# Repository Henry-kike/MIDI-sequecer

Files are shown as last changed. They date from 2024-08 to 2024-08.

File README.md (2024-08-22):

# MIDI-sequecer
***Simple polyphonic MIDI sequencer based in the esp32 with oled display***



I'm looking to combine the best of sequencers like keystep pro and op-1. I make animations for the diferent mode of my sequencer (inspired in the op-1) and i work on adding two track (like keystep pro). The sequencer can save and play chords sequences and i want to add song mode which could play a sequence in different starting notes. Then i will work on playing two sequence simultaneusly, firts on two different MIDI chanels and later in two phisycal MIDI ports.



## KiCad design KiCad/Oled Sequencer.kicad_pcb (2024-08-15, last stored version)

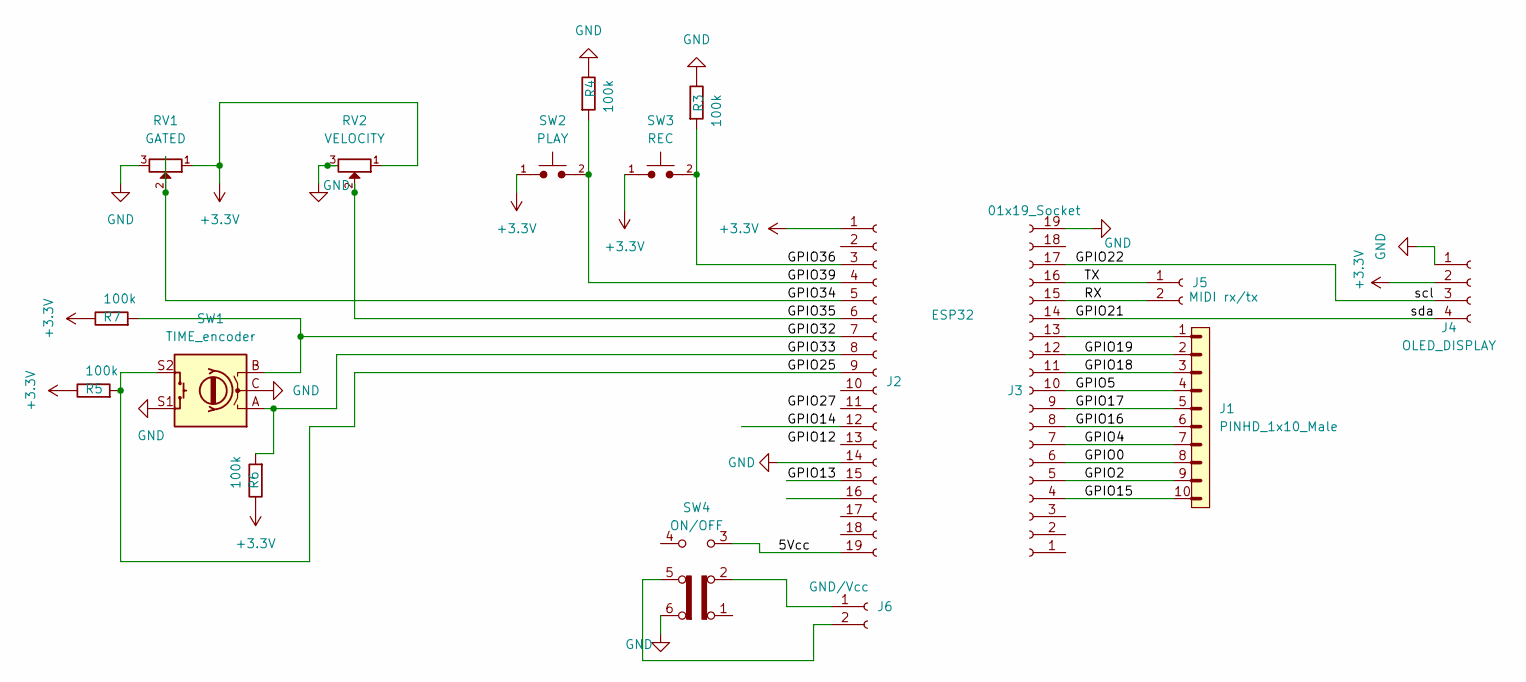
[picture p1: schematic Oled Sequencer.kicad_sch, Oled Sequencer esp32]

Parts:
J1: PINHD_1x10_Male; PinHeader_1x10_P2.54mm_Vertical
J2: ESP32; PinSocket_1x19_P2.54mm_Vertical
J3: 01x19_Socket; PinSocket_1x19_P2.54mm_Vertical
J4: OLED_DISPLAY; PinHeader_1x04_P2.54mm_Vertical
J5: MIDI rx/tx; PinHeader_1x02_P2.54mm_Vertical
J6: GND/Vcc; PinHeader_1x02_P2.54mm_Vertical
R3, R4, R5, R6, R7: 100k; R_Axial_DIN0207_L6.3mm_D2.5mm_P10.16mm_Horizontal
RV1: GATED; Potentiometer_Bourns_PTA2043_Single_Slide
RV2: VELOCITY; Potentiometer_Bourns_PTA2043_Single_Slide
SW1: TIME_encoder; RotaryEncoder_Alps_EC11E-Switch_Vertical_H20mm
SW2: PLAY; SW_PUSH_6mm
SW3: REC; SW_PUSH_6mm
SW4: ON/OFF; SW_E-Switch_EG1271_SPDT

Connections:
+3.3V: J2.1, J4.2, R5.2, R6.2, R7.2, RV1.1, RV2.1, SW2.1, SW3.1
/5Vcc: J2.19, SW4.3 (C)
/GPIO0: J1.8, J3.6
/GPIO2: J1.9, J3.5
/GPIO4: J1.7, J3.7
/GPIO5: J1.4, J3.10
/GPIO13: J2.15
/GPIO14: J2.12
/GPIO15: J1.10, J3.4
/GPIO16: J1.6, J3.8
/GPIO17: J1.5, J3.9
/GPIO18: J1.3, J3.11
/GPIO19: J1.2, J3.12
/GPIO21: J3.14, J4.4
/GPIO22: J3.17, J4.3
/GPIO25: J2.9, R5.1, SW1.S2
/GPIO32: J2.7, R7.1, SW1.B
/GPIO33: J2.8, R6.1, SW1.A
/GPIO34: J2.5, RV1.2
/GPIO35: J2.6, RV2.2
/GPIO36: J2.3, R3.1, SW3.2
/GPIO39: J2.4, R4.1, SW2.2
/RX: J3.15, J5.2
/TX: J3.16, J5.1
GND: J2.14, J3.19, J4.1, R3.2, R4.2, RV1.3, RV2.3, SW1.C, SW1.S1, SW4.6 (C)
unnamed: J1.1, J3.13
unnamed: J6.1, SW4.2 (B)
unnamed: J6.2, SW4.5 (B)

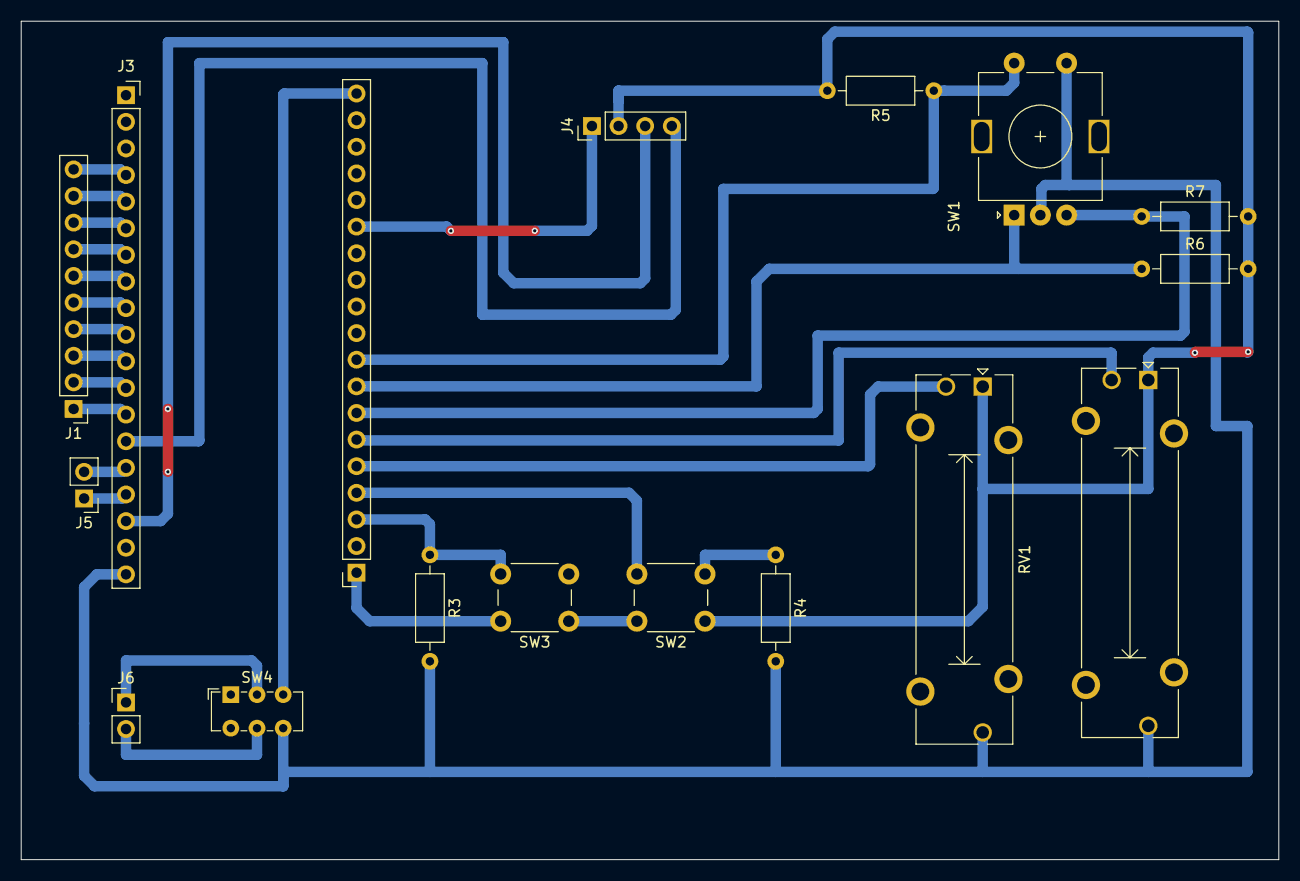
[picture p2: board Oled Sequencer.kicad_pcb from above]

Board: 2 copper layers, 120.0 x 80.0 mm, 17 parts (0 on the bottom side), 26 nets.

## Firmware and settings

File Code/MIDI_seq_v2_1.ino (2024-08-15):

#include "config.h"
#include <MIDI.h>
#include "oled.h"
constexpr bool REC_BUTTON = false;
constexpr bool PLAY_BUTTON = true;

// Declarar el mutex
SemaphoreHandle_t xMutex;
MIDI_CREATE_INSTANCE(HardwareSerial, Serial, midi2);

// Definición de la enumeración para los modos del secuenciador
enum SequencerMode {
  REC_MODE,  // 0
  PLAY_MODE, // 1
  STOP_MODE  // 2
};
//GLOBALS
uint8_t  notes[MAX_NOTES] = {0};  //save the pitch separa con ceros los acordes
uint8_t count=0; //for display and others
uint8_t play_counter=0; //for display numbers in play mode
uint8_t notes_played = 0;
uint8_t notes_press_num = 1;
uint8_t midi_channel = 1;
uint8_t vel_value = 100;
unsigned long sustain = 1200000;
bool is_pressed = false;
volatile uint8_t bpm = 120;
volatile uint8_t figure = QUARTER_NOTE;
volatile bool pressButton = REC_BUTTON; //false = recButton, true = playButton
volatile bool shared_val = false;
volatile bool encoder_change = false;
volatile unsigned long last_interrupt = 0; 
volatile bool encoderButton = false;
unsigned long note_duration = NOTE_DURATION(bpm,figure);
// Variable para almacenar el modo actual del secuenciador
SequencerMode currentMode = REC_MODE;
//INTERRUPT
void IRAM_ATTR play_press();
void IRAM_ATTR rec_press();
void IRAM_ATTR encoder();
void IRAM_ATTR encoder_push();



// Declarar la tarea segundo nucleo
void read_and_display(void *parameter);

//FUNCIONES
int play_notes1(uint8_t notes[], uint8_t channel);
void play_notes(uint8_t *current_note);
void send_notes(uint8_t  **current_note, uint8_t velocity, uint8_t channel, bool prev_val);
void play_sequence();
void stop_sequence();
void rec_sequence();
void rec_reset(bool reset_all);
void add_silence();
void reset_MIDI();
void handleNoteOn(byte channel, byte pitch, byte velocity);
void handleNoteOff(byte channel, byte pitch, byte velocity);
unsigned long sustain_calcule(unsigned long blck);
uint8_t velocity_calcule();

void setup() {
  // Crear el mutex
  xMutex = xSemaphoreCreateMutex();
  // Crear la tarea para actualizar el display OLED en el segundo núcleo
  xTaskCreatePinnedToCore(read_and_display, "Update Display and read values", 4096, NULL, 1, NULL, 0);

  pinMode (LED_BUILTIN, OUTPUT);
  pinMode(PLAY_SWT, INPUT);//pulsador play
  pinMode(REC_SWT, INPUT);//pulsador rec  
  pinMode(ENCODER_SWT, INPUT);
  pinMode(DT, INPUT);
  pinMode(CLK, INPUT);
  pinMode(GATE_PIN,INPUT);
  
  midi2.setHandleNoteOn(handleNoteOn);  // Put only the name of the function       
  midi2.setHandleNoteOff(handleNoteOff);// Do the same for NoteOffs  
  midi2.begin(MIDI_CHANNEL_OMNI);// Initiate MIDI communications, listen to all channels 
  midi2.turnThruOff();   
  attachInterrupt(digitalPinToInterrupt(PLAY_SWT),play_press,FALLING);
  attachInterrupt(digitalPinToInterrupt(REC_SWT),rec_press,FALLING);  
  attachInterrupt(digitalPinToInterrupt(ENCODER_SWT),encoder_push,FALLING); 
  attachInterrupt(digitalPinToInterrupt(CLK),encoder,FALLING);

  display_ini();
  //show hello
  show_intro();  
  rec_sequence();
}



void loop() {
  
  if (pressButton == REC_BUTTON){
    switch(currentMode){
      case REC_MODE:
      rec_reset(true);
      rec_sequence();
      break;

      case PLAY_MODE:
      currentMode = REC_MODE;
      rec_reset(false);
      rec_sequence();
      break;

      case STOP_MODE:
      currentMode = REC_MODE;
      rec_reset(false);
      rec_sequence();
      break;
    }      
  } else{//play pressed
      switch(currentMode){
        case REC_MODE:
        currentMode = PLAY_MODE;
        play_sequence();
        break;

        case PLAY_MODE:
        currentMode = STOP_MODE;
        stop_sequence();
        break;

        case STOP_MODE:
        currentMode = PLAY_MODE;
        play_sequence();
        break;

      }
      
    }

  delay(100); // Añadir un pequeño retardo para evitar rebotes
}

//SUB-MODES
void play_sequence(){
  midi2.setInputChannel(MIDI_CHANNEL_OFF);
  //show_play();
  play_notes(notes);      
  reset_MIDI(); 
}
void stop_sequence(){
  bool prev_val = shared_val;
  
  //show_stop();   
  while(prev_val == shared_val){
    while (Serial.available()>0)  Serial.read();
  } 
}
void rec_sequence(){
  bool prev_val = shared_val;
  show_number(0, true);
  while (prev_val == shared_val){
    midi2.read(MIDI_CHANNEL_OMNI);
    if(encoderButton == true){  //agregar silencio
      add_silence();
      encoderButton = false;    
    }  
  } 
}
void rec_reset(bool reset_all){
  if (reset_all){
    for (int i=0; i<MAX_NOTES; i++){
    notes[i] =  0;
    }
    show_number(0,true);
    digitalWrite(LED_BUILTIN, HIGH);
    delay(200);
    digitalWrite(LED_BUILTIN, LOW);
  }
  
  notes_played = 0;
  count = 0;
  
}

//  SAVE NOTES
void handleNoteOn(byte channel, byte pitch, byte velocity){  
  if (notes_played < (MAX_NOTES-1)){
    notes[notes_played] = pitch;
    notes_played++;

    if (is_pressed == false){
      count++;  
      show_number(count, true);
    }
  }
  else{
    void show_max_notes();
  }  
  is_pressed = true;
}

void handleNoteOff(byte channel, byte pitch, byte velocity){
  if (is_pressed == true && notes_played < MAX_NOTES){ 
    notes[notes_played] = 0;
    notes_played++;
  }
  if (count == 1) midi_channel = channel; //guarda el canal de la primera nota
  is_pressed = false;
}

//  PLAY NOTES  (reproduce en bucle la secuencia hasta que playButton == false)
int play_notes1(uint8_t notes[], uint8_t channel){
  
  uint8_t velocity;
  unsigned long prev_time = 0, sustain_start = 0,sustain_time, note_time;
  bool prev_val = shared_val;  
  uint8_t i = 0, j = 0;
  //Asignacion incial de valores
  if (xSemaphoreTake(xMutex, portMAX_DELAY)) {
      note_time = note_duration;
      sustain_time = sustain;
      velocity = vel_value;
      xSemaphoreGive(xMutex);
    }
  
  while(prev_val == shared_val){
    //tiempo hasta la nota siguiente    
    if((micros() - prev_time) >= note_time){//si cumple un periodo
      prev_time = micros();
       //delay(300);   
      //Encendido de las notas
      while(notes[i] != 0){
        midi2.sendNoteOn(notes[i],vel_value,channel);
        delayMicroseconds(1);//tiempo entre nota y nota, ARPEGIAR (50000)
        i++;
      }
      //SUSTAIN
      sustain_start = micros(); // Usamos una nueva variable para el tiempo de sustain
      //actualizo valores de sustain
      if (xSemaphoreTake(xMutex, portMAX_DELAY)) {
        sustain_time = sustain ;
        xSemaphoreGive(xMutex);
      }
      while ((micros() - sustain_start) <= sustain_time){       
        if (prev_val != shared_val){//si saliste del modo play
          while(notes[j] != 0){//apaga las notas
            midi2.sendNoteOff(notes[j],0,channel);
            delayMicroseconds(1);
            j++;
          }
          return 0;  
        }    
      }
      //apagado de las notas
      while(notes[j] != 0){
        midi2.sendNoteOff(notes[j],0,channel);
        delayMicroseconds(1);
        j++;
      }
      if (xSemaphoreTake(xMutex, portMAX_DELAY)) {
        note_time = note_duration;
        velocity = vel_value;
        play_counter++;
        xSemaphoreGive(xMutex);
      }
      
  if (play_counter >= count){//si termina de tocar todas las notas
    i = 0;
    j = 0;
    play_counter = 0;
  }

      else if (i < MAX_NOTES) {//pasar sobre el cero, avanzar siguiente grupo
        i++;
        j++;     
      }
      
    }
  }
  return 0;
}
void play_notes(uint8_t *current_note){
  uint8_t velocity;
  unsigned long prev_time = 0, note_time;
  bool prev_val = shared_val;  
  
  //Asignacion incial de valores
  if (xSemaphoreTake(xMutex, portMAX_DELAY)) {
      note_time = note_duration;
      velocity = vel_value;
      play_counter = 0;
      xSemaphoreGive(xMutex);
    }
  
  while(prev_val == shared_val){
    //tiempo hasta la nota siguiente    
    if((micros() - prev_time) >= note_time){//si cumple un periodo
      prev_time = micros();

      //Encendido de las notas  
      send_notes(&current_note, velocity, midi_channel, prev_val);

      //actualizo variables
      if (xSemaphoreTake(xMutex, portMAX_DELAY)) {
      note_time = note_duration;
      velocity = vel_value;
      play_counter++;
      current_note++; //warning
      if (play_counter >= count){//si termina de tocar todas las notas   
        play_counter = 0;
        current_note = notes; //reinicia el puntero
      }
      xSemaphoreGive(xMutex);
    }
    }  
  }
}
void send_notes(uint8_t  **current_note, uint8_t velocity, uint8_t channel, bool prev_val){
  unsigned long sustain_start = 0, sustain_time;
  uint8_t *start_note = *current_note;
  while(**current_note != 0){
    midi2.sendNoteOn(**current_note,velocity,channel);
    delayMicroseconds(1);//tiempo entre nota y nota, ARPEGIAR (50000)
    (*current_note)++;
  } 
  //SUSTAIN
  sustain_start = micros(); // Usamos una nueva variable para el tiempo de sustain
  //actualizo valores de sustain
  if (xSemaphoreTake(xMutex, portMAX_DELAY)) {
    sustain_time = sustain ;
    
    xSemaphoreGive(xMutex);
  }
  while ((micros() - sustain_start) <= sustain_time){       
    if (prev_val != shared_val){//si saliste del modo play
      while(*start_note != 0){//apaga las notas
        midi2.sendNoteOff(*start_note,0,channel);
          //delayMicroseconds(1);
          start_note++;
      } 
    }    
  }
  //apagado de las notas
  while(*start_note != 0){//apaga las notas
    midi2.sendNoteOff(*start_note,0,channel);
    //delayMicroseconds(1);
    start_note++;
  }     

}

void add_silence(){
  count++;    
  show_number(count, true);
  if (notes_played < (MAX_NOTES-1)){
    notes[notes_played]=0;
    notes_played++;
  }
  else{
    show_max_notes();
  }
}

void reset_MIDI(){
  while (Serial.available()>0)  Serial.read();
  midi2.begin(MIDI_CHANNEL_OMNI);//reinicia el midi para borrar buffer
  midi2.turnThruOff();  //hay que volverle a decir     
}


//  INTERRUPCIONES:
void IRAM_ATTR play_press(){
  if(millis()-last_interrupt >300)
  {
    pressButton = PLAY_BUTTON;
    shared_val = !shared_val;
    
  }
  last_interrupt=millis();  
}
void IRAM_ATTR rec_press(){
  if(millis()-last_interrupt >300)
  {
    pressButton = REC_BUTTON;
    shared_val = !shared_val;
    
  }
  last_interrupt=millis();  
}

void IRAM_ATTR encoder() {
  if (millis() - last_interrupt > 90) {
    if (xSemaphoreTakeFromISR(xMutex, NULL)) {
      if (digitalRead(DT) == HIGH && bpm < BPM_MAX) {
        bpm++;
      } else if (bpm > BPM_MIN) {
        bpm--;
      }
      encoder_change = true;
      xSemaphoreGiveFromISR(xMutex, NULL);
    }
    last_interrupt = millis();
  }
}

void IRAM_ATTR encoder_push(){
  if(pressButton==REC_BUTTON){  //modo rec
    if(millis()-last_interrupt >200)
    {
      encoderButton=true;  
      last_interrupt=millis();
    }
    
  }
  
  else { //modo play o stop
    encoder_change = true;
    if(millis()-last_interrupt >200)
    {
      if(figure < SIXTEENTH_NOTE){
        figure = figure*2;  
      }
      else{
        figure = WHOLE_NOTE;
      }
      last_interrupt=millis();
    }
  }
}

//SEGUNDO NUCLEO TASK
void read_and_display(void *parameter) {
  //Variables para actualizar el valor solo cuando cambia
  uint8_t currentBpm = bpm;
  uint8_t currentVel = vel_value, oldVel = currentVel;
  uint8_t oldCounter = 0;
  
  
  while (true) {
    // Esperar a que el semáforo sea liberado
    if (encoder_change) {
      update_clock(&currentBpm);
    }

    if (currentMode != REC_MODE){

      if(currentMode == PLAY_MODE){
        if (xSemaphoreTake(xMutex, portMAX_DELAY)) {
          if (oldCounter != play_counter){
            show_number(play_counter+1, false);
            oldCounter = play_counter;
          }          
        xSemaphoreGive(xMutex);
        }
      } 
      else{
        show_stop();
      }
      //VELOCITY
      currentVel = velocity_calcule();
      if (currentVel != oldVel){
      if (xSemaphoreTake(xMutex, portMAX_DELAY)) {
          vel_value = currentVel;       
          xSemaphoreGive(xMutex);
        }
        oldVel = currentVel;
      }
        
      if (xSemaphoreTake(xMutex, portMAX_DELAY)) {
        sustain = sustain_calcule(note_duration);        
        xSemaphoreGive(xMutex);
      }     
    }  

    // Añadir un pequeño delay para evitar actualizaciones excesivas
    vTaskDelay(100 / portTICK_PERIOD_MS);
  }
}
///////////////

void play_sequence_2core(){

}

void update_clock(uint8_t *current_bpm){
  if (xSemaphoreTake(xMutex, portMAX_DELAY)) {
    *current_bpm = bpm;
    note_duration = NOTE_DURATION(*current_bpm, figure);
    encoder_change = false;
    xSemaphoreGive(xMutex);
  }

  show_bpm(*current_bpm);
}
/*
void update_velocity_sustain(){
  //VELOCITY
  currentVel = velocity_calcule();
  if (currentVel != oldVel){
   if (xSemaphoreTake(xMutex, portMAX_DELAY)) {
      vel_value = currentVel;       
      xSemaphoreGive(xMutex);
    }
    oldVel = currentVel;
  }
    
  if (xSemaphoreTake(xMutex, portMAX_DELAY)) {
    sustain = sustain_calcule(note_duration);        
    xSemaphoreGive(xMutex);
  }
}
*/
unsigned long sustain_calcule(unsigned long blck){
  unsigned long m;
  m=(0.8*blck)/4095;//0.8 -> 80%
  return (m*analogRead(GATE_PIN) + blck*GATE_MIN);
}

uint8_t velocity_calcule(){
  int vel = analogRead(VELOCITY_PIN);
  return map(vel, 0, 4096, 10, 127);
}

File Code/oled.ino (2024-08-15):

#include <U8g2lib.h>
#include <Wire.h>
#include <SPI.h>
#include "oled.h"
U8G2_SH1106_128X64_NONAME_F_HW_I2C u8g2(U8G2_R0);

void display_ini(){
  u8g2.begin();
}

void show_intro(void) {
  uint8_t i = 0;
  for (i=0; i<=31; i+=2){
    u8g2.clearBuffer();
    u8g2.setFontMode(1);
    u8g2.setBitmapMode(1);
    u8g2.drawFrame(62-2*i, 31-i, 4+4*i, 2+2*i);//origen
    u8g2.sendBuffer();
    delay(5);
  }
  u8g2.clearBuffer();
  u8g2.setFontMode(1);
  u8g2.setBitmapMode(1);
    u8g2.drawFrame(0, 0, 128, 64);//marco
    u8g2.setFont(u8g2_font_5x8_tr);
    u8g2.drawStr(55, 17, "MIDI");
    u8g2.setFont(u8g2_font_6x13_tr);
    u8g2.drawStr(38, 30, "SEQUENCER");  
    //keyboard:  
    u8g2.drawBox(34, 36, 61, 6);
    u8g2.drawBox(34, 43, 61, 14);
    u8g2.setDrawColor(2);
    u8g2.drawStr(34, 52, "||| || |||");
    u8g2.setFont(u8g2_font_4x6_tr);
    u8g2.drawStr(36, 57, "|  |  |  |  |");
    u8g2.setFont(u8g2_font_6x13_tr);
    u8g2.drawStr(35, 52, "||| || |||");
    u8g2.drawStr(36, 52, "||| || |||");
    u8g2.setFont(u8g2_font_4x6_tr);
    u8g2.drawStr(42, 57, "|  |  |");
    u8g2.drawStr(78, 57, "|  |");
    u8g2.setFont(u8g2_font_6x12_tr);
    u8g2.drawStr(53, 51, "|  |");
  u8g2.sendBuffer();
  delay(3000);
}

void show_play(){
  u8g2.clearBuffer();
  u8g2.setFontMode(1);
  u8g2.setBitmapMode(1);
  u8g2.setFont(u8g2_font_spleen32x64_mf);
  u8g2.drawStr(2, 54, "PLAY");
  u8g2.sendBuffer();
}

void show_stop(){
  u8g2.clearBuffer();
  u8g2.setFontMode(1);
  u8g2.setBitmapMode(1);
  u8g2.setFont(u8g2_font_spleen32x64_mf);
  u8g2.drawStr(2, 54, "STOP");
  u8g2.sendBuffer();
}

void show_number(uint8_t num, bool rec_on){
  char num_char[4];
  itoa(num, num_char, 10);
  u8g2.clearBuffer();
  u8g2.setFontMode(1);
  u8g2.setBitmapMode(1);
  u8g2.setFont(u8g2_font_logisoso50_tf);
  if (num < 10) u8g2.drawStr(46, 60, num_char);
  else if(num >=10) u8g2.drawStr(28, 60, num_char);
  //rec icon 
  if (rec_on){
    u8g2.setDrawColor(1);
    u8g2.drawRBox(101, 0, 27, 7, 2);//rectangulo
    u8g2.setDrawColor(2);
    u8g2.drawEllipse(123, 3, 2, 2);//circulo
    u8g2.setFont(u8g2_font_4x6_tr);
    u8g2.drawStr(106, 6, "REC"); 
  }
      
  u8g2.sendBuffer();
}

void show_bpm(uint8_t bpm){
  char bpm_char[4];
  itoa(bpm, bpm_char, 10);
  u8g2.clearBuffer();
  u8g2.setFontMode(1);
  u8g2.setBitmapMode(1);
  //metronomo icon
  u8g2.drawFrame(13, 43, 18, 8);
  u8g2.drawLine(30, 44, 33, 40);
  u8g2.drawLine(30, 50, 33, 45);
  u8g2.drawLine(33, 41, 33, 44);
  u8g2.drawLine(13, 42, 21, 18);
  u8g2.drawLine(24, 18, 30, 42);
  u8g2.drawLine(21, 18, 23, 18);
  u8g2.drawLine(33, 40, 26, 16);
  u8g2.drawLine(23, 16, 25, 16);
  u8g2.drawLine(22, 43, 12, 24);
  u8g2.drawPixel(25, 18);
  u8g2.drawPixel(22, 17);
  //mesa
  u8g2.drawLine(0, 55, 48, 55);
  u8g2.drawLine(59, 32, 34, 32);
  u8g2.drawLine(48, 55, 60, 33);
  u8g2.drawLine(13, 32, 0, 32);
  //bpm
  u8g2.setFont(u8g2_font_spleen16x32_mf);
  u8g2.drawStr(72, 35, bpm_char);
  u8g2.setFont(u8g2_font_spleen8x16_mf);
  u8g2.drawStr(84, 51, "bpm");
  //
  u8g2.sendBuffer();
}

void show_max_notes()
{
  u8g2.clearBuffer();
  u8g2.setFontMode(1);
  u8g2.setBitmapMode(1);
  u8g2.setFont(u8g2_font_profont29_tr);
  u8g2.drawStr(49, 28, "NO");
  u8g2.drawStr(33, 54, "MORE");
  u8g2.drawFrame(0, 0, 128, 64);
  u8g2.sendBuffer();
}

void show_sustain(int gate){//espera un valor de analogRead
  gate = map(gate, 0, 4096, 0, 6);
  u8g2.clearBuffer();
  u8g2.setFontMode(1);
  u8g2.setBitmapMode(1);
  switch (gate) {
    
    case 0:   
      u8g2.drawBox(20, 33, 12, 12);
      u8g2.drawFrame(34, 33, 12, 12);
      u8g2.drawFrame(48, 33, 12, 12);
      u8g2.drawFrame(62, 33, 12, 12);
      u8g2.drawFrame(76, 33, 12, 12);
      u8g2.drawFrame(90, 33, 12, 12);
      break;    

      case 1:   
      u8g2.drawBox(20, 33, 12, 12);
      u8g2.drawBox(34, 33, 12, 12);
      u8g2.drawFrame(48, 33, 12, 12);
      u8g2.drawFrame(62, 33, 12, 12);
      u8g2.drawFrame(76, 33, 12, 12);
      u8g2.drawFrame(90, 33, 12, 12);
      break;

      case 2:   
      u8g2.drawBox(20, 33, 12, 12);
      u8g2.drawBox(34, 33, 12, 12);
      u8g2.drawBox(48, 33, 12, 12);
      u8g2.drawFrame(62, 33, 12, 12);
      u8g2.drawFrame(76, 33, 12, 12);
      u8g2.drawFrame(90, 33, 12, 12);
      break;

      case 3:   
      u8g2.drawBox(20, 33, 12, 12);
      u8g2.drawBox(34, 33, 12, 12);
      u8g2.drawBox(48, 33, 12, 12);
      u8g2.drawBox(62, 33, 12, 12);
      u8g2.drawFrame(76, 33, 12, 12);
      u8g2.drawFrame(90, 33, 12, 12);
      break; 

      case 4:   
      u8g2.drawBox(20, 33, 12, 12);
      u8g2.drawBox(34, 33, 12, 12);
      u8g2.drawBox(48, 33, 12, 12);
      u8g2.drawBox(62, 33, 12, 12);
      u8g2.drawBox(76, 33, 12, 12);
      u8g2.drawFrame(90, 33, 12, 12);
      break;  

      case 5:   
      u8g2.drawBox(20, 33, 12, 12);
      u8g2.drawBox(34, 33, 12, 12);
      u8g2.drawBox(48, 33, 12, 12);
      u8g2.drawBox(62, 33, 12, 12);
      u8g2.drawBox(76, 33, 12, 12);
      u8g2.drawBox(90, 33, 12, 12);
      break;    
  }
  
  u8g2.setFont(u8g2_font_spleen6x12_mf);
  u8g2.drawStr(41, 21, "sustain");
  //u8g2.drawLine(1, 8, 123, 8);
  //u8g2.drawLine(0, 24, 122, 24);
  u8g2.sendBuffer();
}

void show_figure(uint8_t fig){
  switch(fig){
    case WHOLE_NOTE:
    u8g2.clearBuffer();
    u8g2.setFontMode(1);
    u8g2.setBitmapMode(1);
    u8g2.drawFilledEllipse(65, 29, 30, 21);
    u8g2.setDrawColor(0);
    u8g2.drawFilledEllipse(65, 29, 23, 20);
    u8g2.setDrawColor(1);
    u8g2.sendBuffer();
    break;

    case HALF_NOTE:
    u8g2.clearBuffer();
    u8g2.setFontMode(1);
    u8g2.setBitmapMode(1);
    u8g2.drawFilledEllipse(58, 43, 10, 7);
    u8g2.drawBox(65, 9, 4, 32);
    u8g2.setDrawColor(0);
    u8g2.drawFilledEllipse(58, 43, 7, 4);
    u8g2.setDrawColor(1);
    
    u8g2.sendBuffer();       
    break;

    case QUARTER_NOTE:
    u8g2.clearBuffer();
    u8g2.setFontMode(1);
    u8g2.setBitmapMode(1);
    u8g2.drawFilledEllipse(58, 43, 10, 7);
    u8g2.drawBox(65, 9, 4, 32);
    u8g2.sendBuffer();
    break;

    case EIGHTH_NOTE:
    u8g2.clearBuffer();
    u8g2.setFontMode(1);
    u8g2.setBitmapMode(1);
    u8g2.drawFilledEllipse(44, 43, 10, 7);
    u8g2.drawFilledEllipse(72, 43, 10, 7);
    u8g2.drawBox(51, 9, 4, 32);
    u8g2.drawBox(79, 9, 4, 32);
    u8g2.drawBox(55, 9, 24, 4);
    u8g2.sendBuffer();
    break;
    
    case SIXTEENTH_NOTE:
    u8g2.clearBuffer();
    u8g2.setFontMode(1);
    u8g2.setBitmapMode(1);
    u8g2.drawFilledEllipse(19, 43, 10, 7);
    u8g2.drawFilledEllipse(47, 43, 10, 7);
    u8g2.drawBox(26, 9, 4, 32);
    u8g2.drawBox(54, 9, 4, 32);
    u8g2.drawBox(30, 18, 24, 4);
    u8g2.drawBox(30, 9, 24, 4);
    u8g2.drawFilledEllipse(75, 43, 10, 7);
    u8g2.drawFilledEllipse(103, 43, 10, 7);
    u8g2.drawBox(82, 9, 4, 32);
    u8g2.drawBox(110, 9, 4, 32);
    u8g2.drawBox(86, 18, 24, 4);
    u8g2.drawBox(86, 9, 24, 4);
    u8g2.drawBox(58, 18, 24, 4);
    u8g2.drawBox(58, 9, 24, 4);
    u8g2.sendBuffer();
    break;
  }
  
}
